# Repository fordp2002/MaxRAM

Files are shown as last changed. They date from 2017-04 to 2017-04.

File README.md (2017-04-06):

# MaxRAM
Open Hardware BBC RAM/ROM Board

My current thoughts are a board that covers the BBCs 4 sideways ROM sockets and has the following features:
1 4 MBit (512KB) 32 Pin DIP Flash Chip (Socketed) [Microchip Technology SST39SF040-70-4C-PHE]
1 4 Mbit (512KB) SRAM Chip [Alliance Memory, Inc. AS6C4008-55PCN]
1 PLD to handle the logic [ATF1502ASL-25JU44-ND]
1 Simple diode battery backup circuit and battery connector or maybe an IC [DS1210S+TRL-ND] for Battery Backup.

Slot 15 will contain the ROM Manager.
8 Slots will be Write Protected RAM.
8 Slots will be Read Write RAM.
16 pages of Flash will be selected at power on with the ability to switch to 16 pages of RAM after boot.

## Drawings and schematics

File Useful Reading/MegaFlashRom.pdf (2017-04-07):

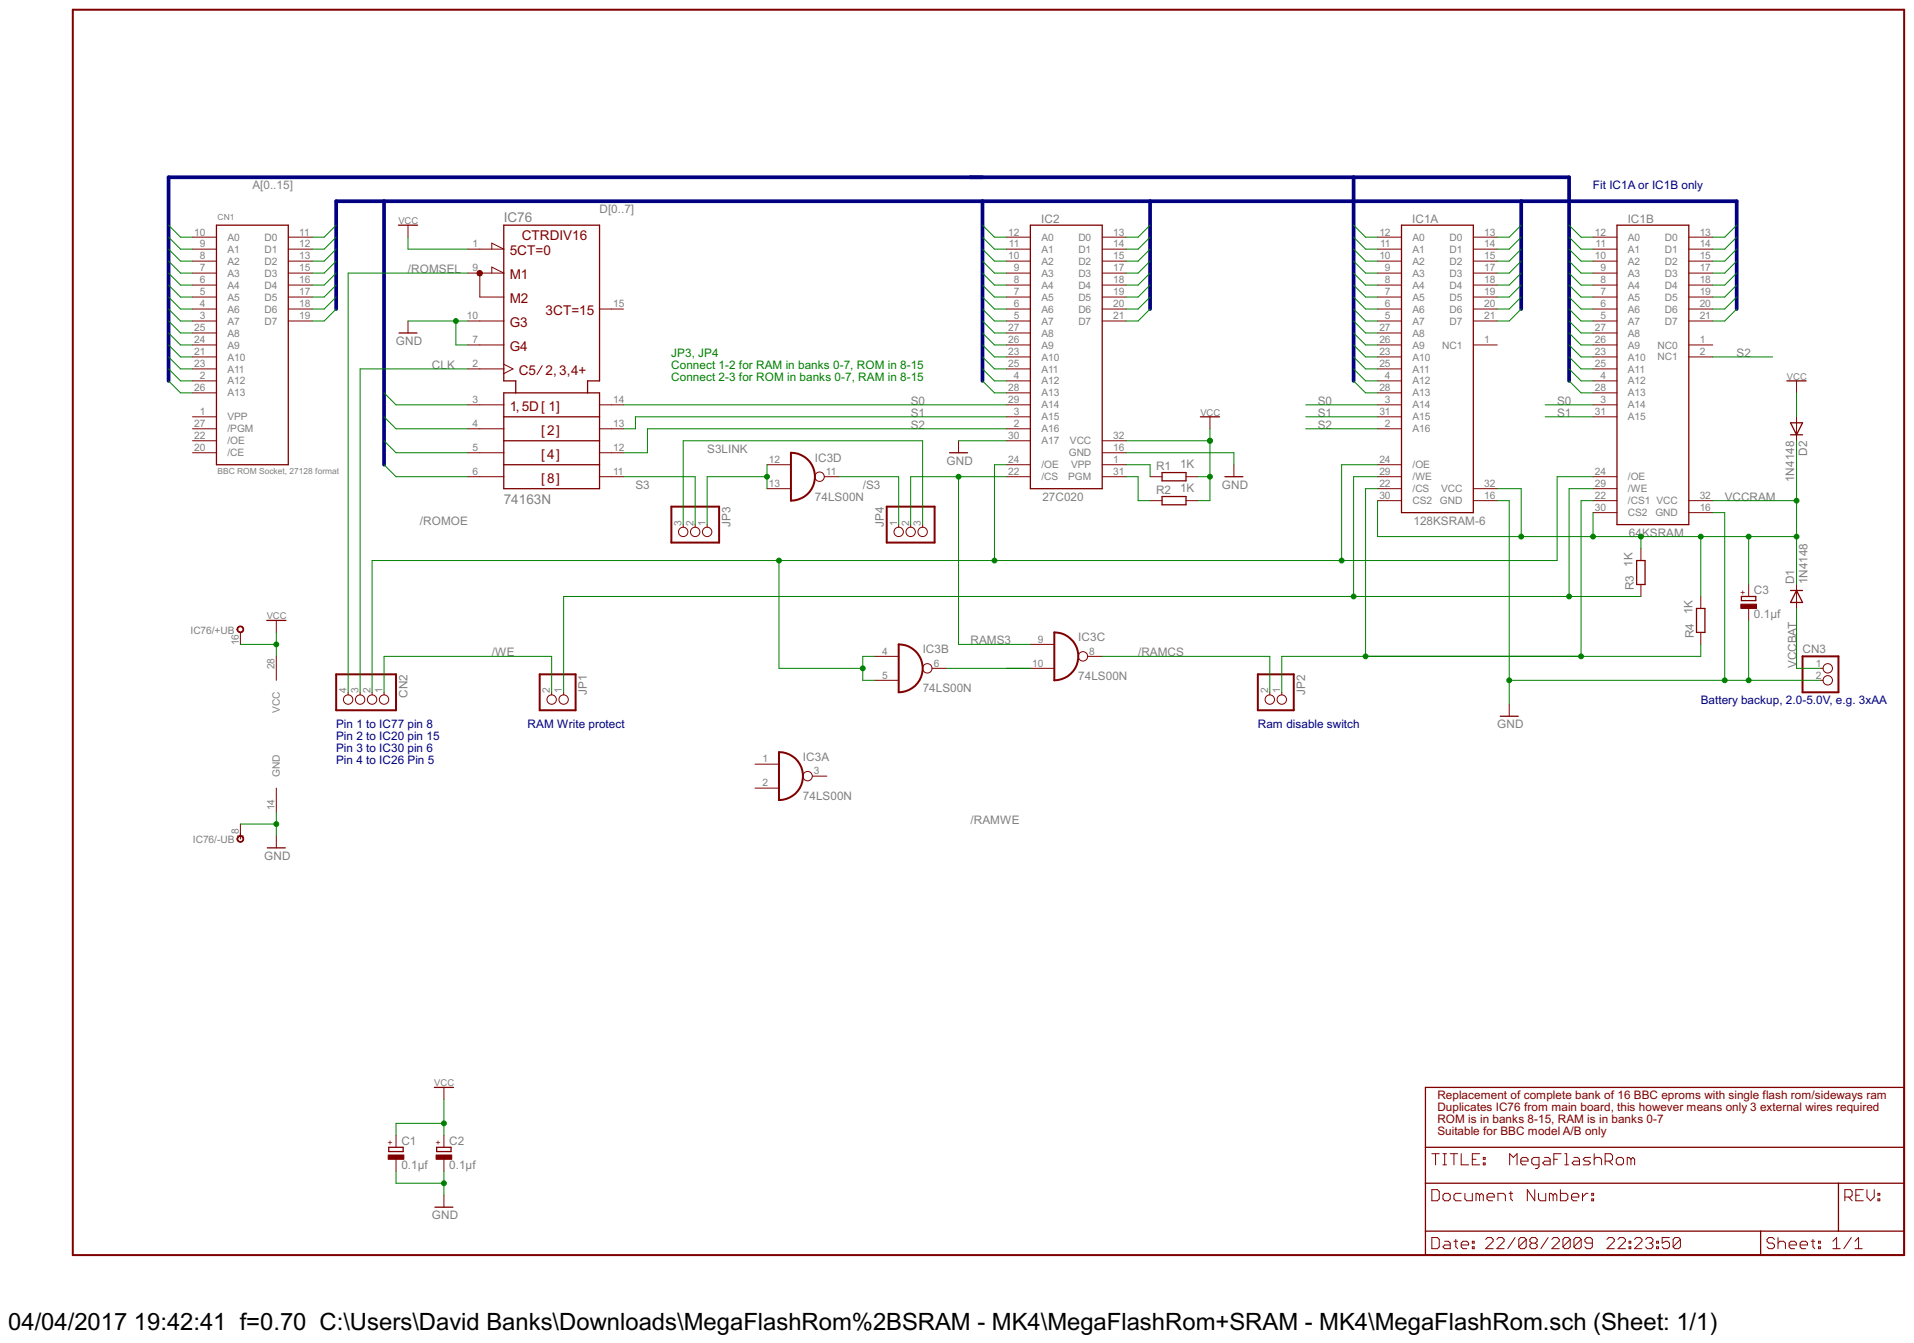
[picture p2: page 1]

JP3, JP4 Connect 1-2 for RAM in banks 0-7, ROM in 8-15 Connect 2-3 for ROM in banks 0-7, RAM in 8-15

BBC ROM Socket, 27128 format

Replacement of complete bank of 16 BBC eproms with single flash rom/sideways ram
Duplicates IC76 from main board, this however means only 3 external wires required ROM is in banks 8-15, RAM is in banks 0-7 Suitable for BBC model A/B only

04/04/2017 19:42:41 f=0.70 C:\Users\David Banks\Downloads\MegaFlashRom%2BSRAM - MK4\MegaFlashRom+SRAM - MK4\MegaFlashRom.sch (Sheet: 1/1)

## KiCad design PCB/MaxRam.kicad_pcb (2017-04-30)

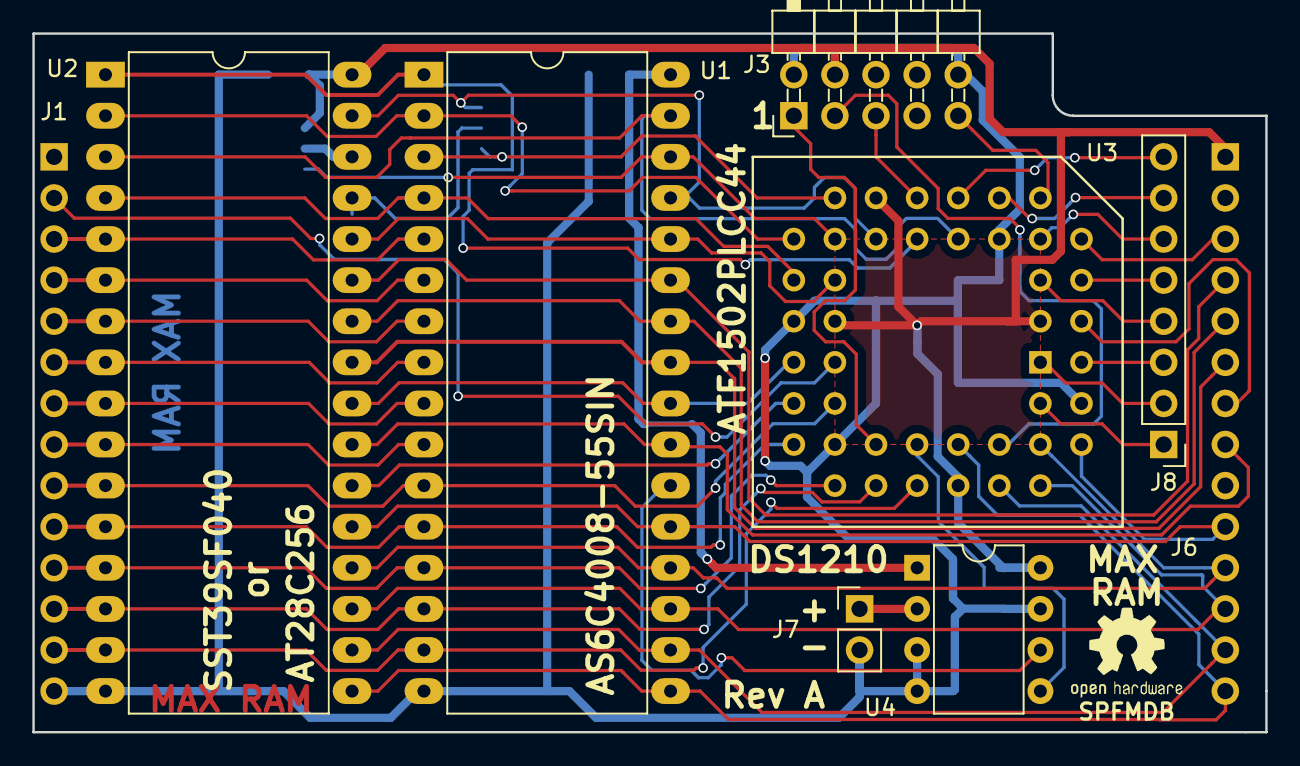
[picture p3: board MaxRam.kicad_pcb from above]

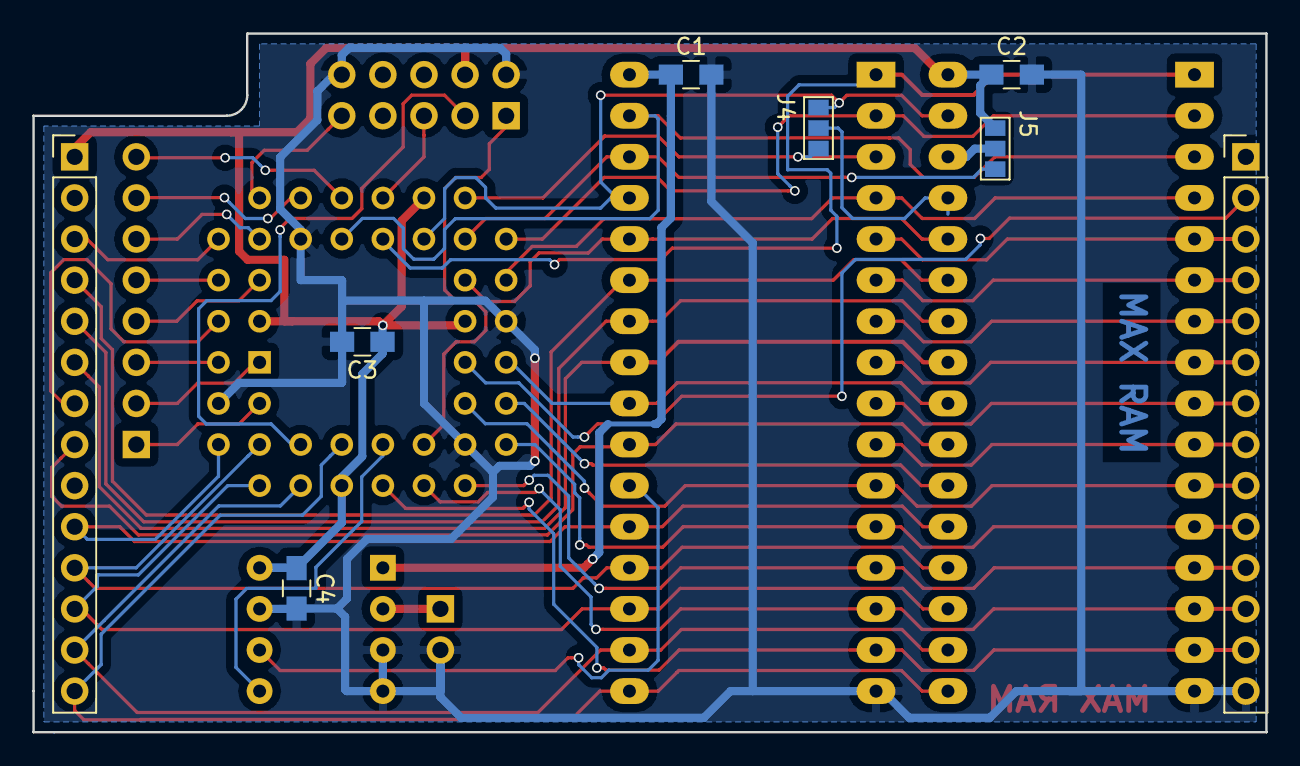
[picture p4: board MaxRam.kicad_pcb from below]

Board: 2 copper layers, 76.2 x 43.2 mm, 15 parts (8 on the bottom side), 53 nets.

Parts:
C1, C2, C3, C4: C; C_0805_HandSoldering
J1, J6: CONN_01X14; Pin_Header_Straight_1x14_Pitch2.54mm
J3: CONN_02X05; Pin_Header_Angled_2x05_Pitch2.54mm
J4, J5: GS3
J7: CONN_01X02; Pin_Header_Straight_1x02_Pitch2.54mm
J8: CONN_01X08; Pin_Header_Straight_1x08_Pitch2.54mm
U1: AS6C4008-55SIN; DIP-32_W15.24mm_LongPads
U2: SST39SF040; DIP-32_W15.24mm_LongPads
U3: ATF1502PLCC44; PLCC44
U4: DS1210; DIP-8_W7.62mm

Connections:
+5V: C2.1, C3.1, C4.1, J3.4, J5.1, J6.1, U2.32, U3.3, U3.15, U3.23, U3.35, U4.8
/A0: J1.10, U1.12, U2.12, U3.28
/A1: J1.9, U1.11, U2.11, U3.27
/A2: J1.8, U1.10, U2.10
/A3: J1.7, U1.9, U2.9
/A4: J1.6, U1.8, U2.8
/A5: J1.5, U1.7, U2.7
/A6: J1.4, U1.6, U2.6
/A7: J1.3, U1.5, U2.5
/A8: J6.4, U1.27, U2.27
/A9: J6.5, U1.26, U2.26
/A10: J6.8, U1.23, U2.23
/A11: J6.6, U1.25, U2.25
/A12: J1.2, U3.25
/A13: J6.3, U3.6
/BAT: J7.1, U4.2
/CLK: J8.1, U3.43
/CS_in: J8.8, U3.11
/CsIn: J8.2, U3.1
/D0: J1.11, U1.13, U2.13, U3.29
/D1: J1.12, U1.14, U2.14, U3.31
/D2: J1.13, U1.15, U2.15, U3.33
/D3: J6.14, U1.17, U2.17, U3.36
/D4: J6.13, U1.18, U2.18, U3.37
/D5: J6.12, U1.19, U2.19, U3.39
/D6: J6.11, U1.20, U2.20, U3.41
/D7: J6.10, U1.21, U2.21, U3.40
/FLASH_nCE: U2.22, U3.26
/OE_IN: J6.7, U3.2
/PIN29: J4.2, U2.29
/PIN30: J5.2, U2.30
/RAM_nCE: U1.22, U4.6
/Romsel: J8.3, U3.44
/S12: U1.4, U2.4, U3.20
/S13: U1.28, U2.28, U3.21
/S14: J4.3, U1.3, U3.17
/S15: U1.31, U2.3, U3.12
/S16: U1.2, U2.2, U3.18
/S17: J5.3, U1.30, U3.19
/S18: U1.1, U2.1, U3.14
/TCK: J3.1, U3.32
/TDI: J3.9, U3.7
/TDO: J3.3, U3.38
/TMS: J3.5, U3.13
/VBAT: C1.1, U1.32, U4.1
/Z1: J8.4, U3.5
/Z2: J8.5, U3.4
/Z3: J8.6, U3.8
/Z4: J8.7, U3.9
/nOE: U1.24, U2.24, U3.24
/nWE: J4.1, U1.29, U2.31, U3.16
GND: C1.2, C2.2, C3.2, C4.2, J1.14, J3.2, J3.10, J7.2, U1.16, U2.16, U3.10, U3.22, U3.30, U3.42, U4.3, U4.4, U4.7
unnamed: U3.34, U4.5

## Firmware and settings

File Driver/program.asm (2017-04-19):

; SST39SF010 flash programmer
; by Phillip Pearson

; Copyright 2017 Google Inc
; Licensed under the GPL; see LICENSE.txt for details.


; You'll need ca65 and ld65 (from cc65) to assemble and link this.

; In MODE 6, the screen starts at &6000.  If we want to stage a
; 16 kB ROM image for programming, we can load it in at &2000.
; If we build this flasher code to run at &1100, we have &F00
; (3840) bytes to play with.  Right now this clocks in at under
; 1k, so there's plenty of room to move!

; On an Electron with a Plus 1 but no other interesting interfaces,
; the easiest way I've found to get data in for flashing is to use
; a 3.5mm to Bang & Olufsen cable to connect a laptop to the
; cassette port, and use UEFtrans.py and uef2wave.py to convert the
; file into a UEF and then a WAV.  First load the file with:

; On the Electron: *LOAD image 2000
; On the laptop: python file_to_wav.py image.rom image 2000

; Then build and run this file.  Edit erase_cart_first and
; rom_to_program (further down) for configuration.

; On the Electron: *RUN
; On the laptop: make

; It should select bank 0 or 1 and flash from &8000-&BFFF.  No
; verification is performed yet.


; Zero page addresses (stolen from Econet) for indirect accesses
zp_lo := $90
zp_hi := $91

; OS call to write a character to the screen
OSWRCH := $FFEE

; --- program entry point ---
entry_point:
	JMP main

; --- 'puts' macro ---
puts_pos: .byte $00 ; string position
.macro	puts	addr
.proc
	lda #0
	sta puts_pos
write_byte:
	ldx puts_pos
	lda addr, x
	cmp #0
	beq done
	jsr OSWRCH
	inc puts_pos
	jmp write_byte
done:
.endproc
.endmacro

; --- strings ---

probing_cart0_msg:
	.byte "Probing cart 0"
	.byte $0D
	.byte $0A
	.byte $00
probing_cart2_msg:
	.byte "Probing cart 2"
	.byte $0D
	.byte $0A
	.byte $00
programming_bank_msg:
	.byte "Programming bank "
	.byte $00
all_done_msg:
	.byte "All done!"
	.byte $0D
	.byte $0A
	.byte $00
programming_msg:
	.byte "Programming..."
	.byte $0D
	.byte $0A
	.byte $00
blank_msg:
	.byte "ROM is blank!"
	.byte $0D
	.byte $0A
	.byte $00
waiting_msg:
	.byte "Waiting..."
	.byte $0D
	.byte $0A
	.byte $00
erasing_msg:
	.byte "Erasing..."
	.byte $0D
	.byte $0A
	.byte $00
done_msg:
	.byte "Done."
	.byte $0D
	.byte $0A
	.byte $00
crlf:
	.byte $0D
	.byte $0A
	.byte $00

; --- main (called from .entry_point) ---
previous_rom: .byte $00
erase_cart_first: .byte $00 ; erases if 1
rom_to_program: .byte $01 ; bank 00 or 01
main:
	; stash initial ROM ID
	lda $f4
	sta previous_rom

	; probe cartridge 0,1
	puts probing_cart0_msg
	LDA #0
	JSR identify_flash_chip

	puts programming_bank_msg
	lda rom_to_program
	jsr write_hex_byte
	puts crlf

	; do we need to erase the chip first?
	lda erase_cart_first
	cmp #0
	beq main__erase_done
	jsr erase_whole_chip
main__erase_done:

	lda rom_to_program
	jsr select_rom
	jsr program_16k_rom
	jsr blank_check

	; probe cartridge 2,3
	;puts probing_cart2_msg
	;LDA #2
	;JSR select_rom
	;JSR identify_flash_chip

back_to_basic:
	puts all_done_msg
	lda previous_rom
	jsr select_rom
	RTS

hang:
	puts all_done_msg
	JMP hang

; A = number to write (0-15)
write_hex_char:
	CMP #10
	BCC less_than_ten
	CLC
	ADC #55 ; add 'A' - 10
	JMP print_it
less_than_ten:
	CLC
	ADC #48 ; add '0'
print_it:
	jsr OSWRCH
	RTS

; A = byte to write
write_hex_byte:
	PHA ; stash a copy of the char
	AND #$F0
	LSR
	LSR
	LSR
	LSR
	JSR write_hex_char ; write high nybble
	PLA ; get the char back in A
	AND #$0F
	JSR write_hex_char ; write low nybble
	RTS

; X, Y = address to write
; roughly: printf("%02x%02x\r\n", y, x)
write_hex_address:
	; stash x and y for later
	txa
	pha
	tya
	pha
	; and stash x (low byte) again
	txa
	pha
	; now write y (high byte)
	tya
	jsr write_hex_byte
	; and x
	pla
	jsr write_hex_byte
	puts crlf
	; and get x and y back
	pla
	tay
	pla
	tax
	rts

; put the cartridge in the 0/1 slot
; A = rom ID to select (0-3)
select_rom:
	STA zp_lo   ; save ROM ID

	LDA #12   ; deselect BASIC
	STA $F4
	STA $FE05

	LDA zp_lo   ; load ROM ID
	STA $F4
	STA $FE05

	RTS

; we need to be able to write to addresses 2AAA and 5555 (A14-A0; don't care about A15+)
; A16 = ROMQA (bank ID)
; A15 = 0
; A14 = A12
; A13-A0 map into $8000-$BFFF
; so we select the low bank (rom_id), then:
; 2AAA = 010 1010 1010 1010, i.e. A13:0 = 2AAA, + 8000 = AAAA
; 5555 = 101 0101 0101 0101, i.e. A13:0 = 1555, + 8000 = 9555

; flash chip identification
; A = base rom ID to select (0 or 2)
rom_id: .byte $00
chip_id: .byte $00
identify_flash_chip:
	STA rom_id
	JSR select_rom

	; * enter flash ID mode

	; write AA to 5555
	LDA #$AA
	STA $9555

	; write 55 to 2AAA
	LDA #$55
	STA $AAAA

	; write 90 to 5555
	LDA #zp_lo
	STA $9555

	; * read chip identifying info

	; read 0000, should be $BF
	LDA $8000
	JSR write_hex_byte
	puts crlf

	; read 0001, should be $B5 (or B6 for 39SF020A, B7 for 39SF040)
	LDA $8001
	JSR write_hex_byte
	puts crlf

	; * exit flash ID mode

	; write AA to 5555
	LDA #$AA
	STA $9555

	; write 55 to 2AAA
	LDA #$55
	STA $AAAA

	; write F0 to 5555
	LDA #$F0
	STA $9555

	RTS

blank_check:
	; counter
	lda #0
	sta zp_lo
	lda #$80
	sta zp_hi

blank_check__loop:
	ldy #0
	lda (zp_lo), y
	cmp #0
	bne blank_check__not_blank ; not blank

	; increment zp_lo, zp_hi
	clc
	lda zp_lo
	adc #1
	sta zp_lo
	lda zp_hi
	adc #1
	sta zp_hi

	; are we at the end of the rom space?
	cmp #$c0
	bne blank_check__loop

	puts blank_msg ; if we get here, it's blank!

blank_check__done:
	RTS

blank_check__not_blank:
	ldx #0
	ldy zp_hi
	jmp dump_page

; --- programming ---
; A = byte to write
; X, Y = low/high bytes of address to write to (in 8000-BFFF)
; this assumes the correct bank is already selected and the sector is erased
program_byte:
	STX zp_lo ; write X,Y,A to zp_lo
	STY zp_hi
	STA $03

	; * write four command bytes
	; write AA to 5555
	LDA #$AA
	STA $9555
	; write 55 to 2AAA
	LDA #$55
	STA $AAAA
	; write A0 to 5555
	LDA #$A0
	STA $9555
	; * write data to address
	LDA $03
	LDX #0
	STA (zp_lo, X)

	; * poll toggle bit until the program operation is complete
	JSR wait_until_operation_done

	RTS

; --- program 16kB rom from $2000 into bank 0 ---
; this assumes the correct bank is already selected
; and the data to program is from $2000-$6000
; (you probably want to be in MODE 6)
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

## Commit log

2017-04-13 More useful reading
    [MegaFlashRom.brd, MegaFlashRom.sch]
2017-04-17 Add the BBC Circuit diagram
2017-04-17 Add KiCad Files
    [MaxRam.kicad_pcb, MaxRam.sch]
2017-04-17 Update PCB Still getting used to KiCad / PCB Design
    [MaxRam.kicad_pcb, MaxRam.sch]
2017-04-19 Assembly code to erase and byte-program SST39SF010A flash
2017-04-19 Add PCB with CPLD at rats nest
    [MaxRam.kicad_pcb, MaxRam.sch]
2017-04-20 PCB all routed
    [MaxRam.kicad_pcb, MaxRam.sch]
2017-04-22 PCB now has a ground plane (copper pour)
    [MaxRam.kicad_pcb]
2017-04-22 Latest PCB including plane and pin swapped CPLD, still messy
    [MaxRam.kicad_pcb, MaxRam.sch]
2017-04-26 Work in progress, about to fix overlapping parts
    [MaxRam.kicad_pcb, MaxRam.sch]
2017-04-27 Latest design. PLCC now on it's own, a bit more tweaking yet.
    [MaxRam.kicad_pcb, MaxRam.sch]
2017-04-28 All fixed up version
    [MaxRam.kicad_pcb, MaxRam.sch]
2017-04-30 Post up Issue A as sent to OSH Park
    [MaxRam.kicad_pcb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]
2017-04-30 Update HDL to match the latest design. Very basic design at the moment.
    [MaxRam.sch]
